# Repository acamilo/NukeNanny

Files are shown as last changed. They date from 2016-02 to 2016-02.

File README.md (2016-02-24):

# NukeNanny
Sensor Node for beehive data collection. 433mhz radio. temp/humidity/ optionally weight.

## Sensors
 * Humidity/Temp (HTU21D)
 * two optional load cells (HX711)

## Radio
 * 433mhz nrf9e5 8051 CPU + Radio
 * 10dBm Tx. 10mm helical antenna 2.5dBi
 
## Battery
 * CR2032 (225mAh)
 * [Rough power budget](https://docs.google.com/spreadsheets/d/1PkM406ndirrwiI1R5EvJM8zMfThP9lIQZCE76__e_ts/edit?usp=sharing) (avg draw 16uA)

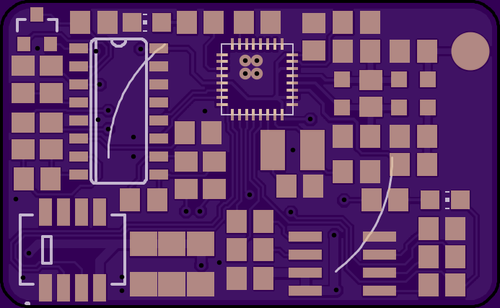
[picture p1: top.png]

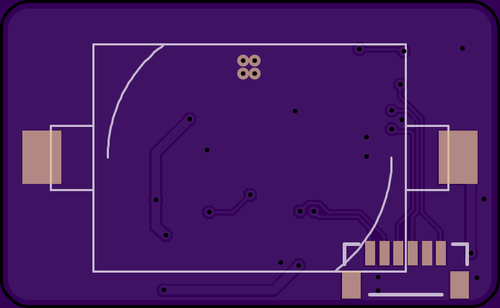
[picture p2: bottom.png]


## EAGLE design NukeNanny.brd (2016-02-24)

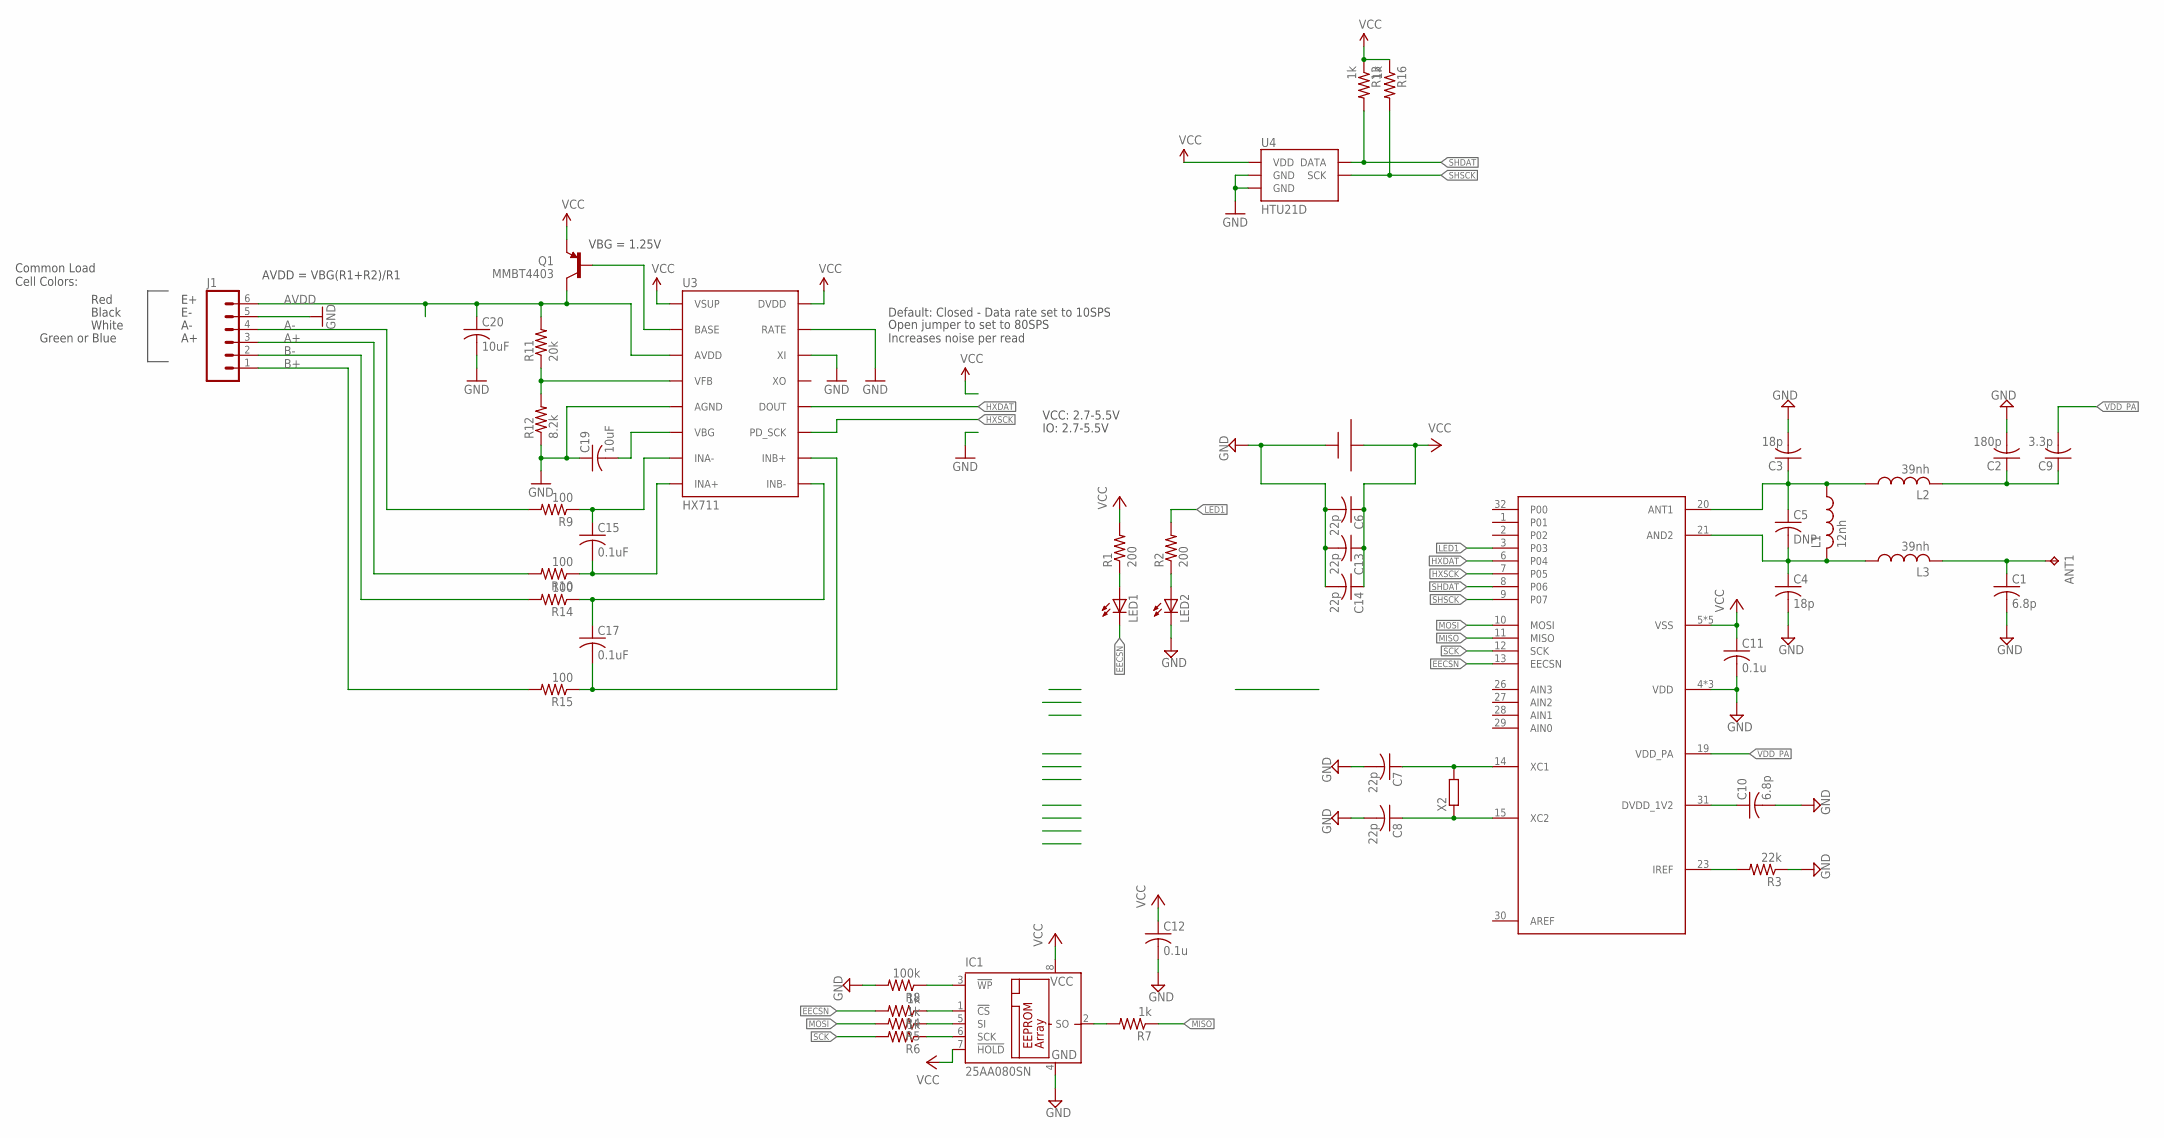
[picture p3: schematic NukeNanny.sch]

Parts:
ANT1: TPB2,54; B2,54
C1, C10: 6.8p; C0805
C2: 180p; C0805
C3, C4: 18p; C0805
C5: DNP; C0805
C6, C13, C14: 22p; C1206
C7, C8: 22p; C0805
C9: 3.3p; C0805
C11, C12: 0.1u; C0805
C15, C17: 0.1uF; C0805
C19, C20: 10uF; C0805
IC1: 25AA080SN; SO-08
J1: M06SMD-1MM; 1X06-1MM
L1: 12nh; L2012C
L2, L3: 39nh; L2012C
LED1, LED2: LEDCHIP-LED0805; CHIP-LED0805
Q1: MMBT4403; SOT23-3
R1, R2: 200; R0805
R3: 22k; R0805
R4, R5, R6, R7, R13, R16: 1k; R0805
R8: 100k; R0805
R9, R10, R14, R15: 100; R0805
R11: 20k; R0805
R12: 8.2k; R0805
U1: CR2032; SMT_CR2032_HOLDER
U3: HX711; SO16
U4: HTU21D
U$1: NRF9E5; 32QFN-THIN
X2: R-EU_R3225; R3225

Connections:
A+: J1.3, R10.2
A-: J1.4, R9.2
AVDD: C20.1, J1.6, Q1.3 (C), R11.2, U3.3 (AVDD)
B+: J1.1, R15.2
B-: J1.2, R14.2
EECSN: LED1.C, R4.2, U$1.13 (EECSN)
GND: C1.2, C2.2, C3.2, C4.2, C6.2, C7.2, C8.2, C10.2, C11.2, C12.2, C13.2, C14.2, C19.1, C20.2, IC1.4 (GND), J1.5, LED2.C, R3.1, R8.2, R12.1, U1.-, U3.5 (AGND), U3.14 (XI), U3.15 (RATE), U4.7 (GND), U4.GND, U$1.4 (VDD), U$1.17 (VDD), U$1.25 (VDD)
HXDAT: U3.12 (DOUT), U$1.6 (P04)
HXSCK: U3.11 (PD_SCK), U$1.7 (P05)
LED1: R2.2, U$1.3
MISO: R7.1, U$1.11 (MISO)
MOSI: R5.2, U$1.10 (MOSI)
unnamed: C4.1, C5.2, L1.2, L3.1, U$1.21 (AND2)
unnamed: C3.1, C5.1, L1.1, L2.1, U$1.20 (ANT1)
unnamed: C10.1, U$1.31 (DVDD_1V2)
unnamed: C2.1, C9.1, L2.2
unnamed: LED1.A, R1.1
unnamed: LED2.A, R2.1
unnamed: ANT1.TP, C1.1, L3.2
unnamed: C8.1, U$1.15 (XC2), X2.1
unnamed: C7.1, U$1.14 (XC1), X2.2
unnamed: IC1.1 (!CS), R4.1
unnamed: IC1.5 (SI), R5.1
unnamed: IC1.6 (SCK), R6.1
unnamed: IC1.2 (SO), R7.2
unnamed: R3.2, U$1.23 (IREF)
unnamed: IC1.3 (!WP), R8.1
unnamed: Q1.1 (B), U3.2 (BASE)
unnamed: R11.1, R12.2, U3.4 (VFB)
unnamed: C19.2, U3.6 (VBG)
unnamed: C17.1, R14.1, U3.9 (INB-)
unnamed: C15.1, R9.1, U3.7 (INA-)
unnamed: C15.2, R10.1, U3.8 (INA+)
unnamed: C17.2, R15.1, U3.10 (INB+)
SCK: R6.2, U$1.12 (SCK)
SHDAT: R13.2, U4.DATA, U$1.8 (P06)
SHSCK: R16.2, U4.SCK, U$1.9 (P07)
VCC: C6.1, C11.1, C12.1, C13.1, C14.1, IC1.7 (!HOLD), IC1.8 (VCC), Q1.2 (E), R1.2, R13.1, R16.1, U1.+, U3.1 (VSUP), U3.16 (DVDD), U4.VDD, U$1.5 (VSS), U$1.16 (VSS), U$1.18 (VSS), U$1.22 (VSS), U$1.24 (VSS)
VDD_PA: C9.2, U$1.19 (VDD_PA)

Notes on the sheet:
VCC: 2.7-5.5V
VBG = 1.25V
AVDD = VBG(R1+R2)/R1
Default: Closed - Data rate set to 10SPS
Open jumper to set to 80SPS Increases noise per read
Red
Black
White
Green or Blue
Common Load Cell Colors:
IO: 2.7-5.5V

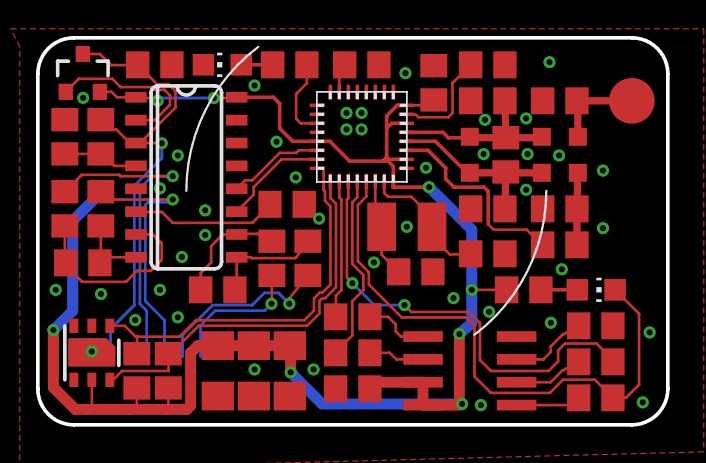
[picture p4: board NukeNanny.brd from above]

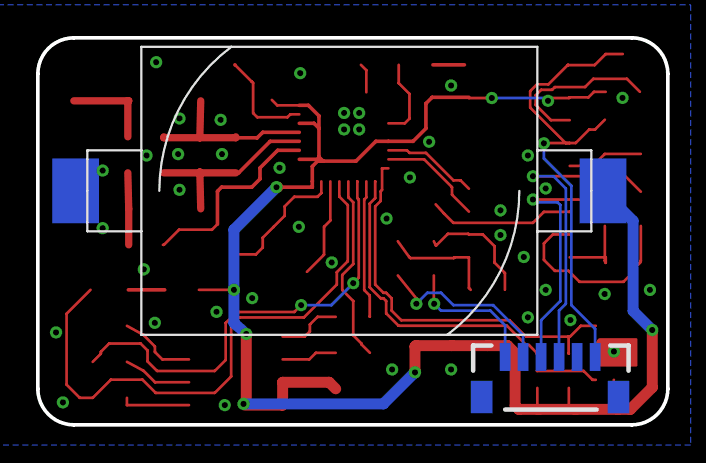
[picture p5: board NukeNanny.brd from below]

Board: 2 copper layers, 35.0 x 21.5 mm, 48 parts (2 on the bottom side), 39 nets.

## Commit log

2016-02-23 Layout done
    [NukeNanny.brd, NukeNanny.sch]
2016-02-24 Changed sensor to HTU21D
    [NukeNanny.brd, NukeNanny.sch]

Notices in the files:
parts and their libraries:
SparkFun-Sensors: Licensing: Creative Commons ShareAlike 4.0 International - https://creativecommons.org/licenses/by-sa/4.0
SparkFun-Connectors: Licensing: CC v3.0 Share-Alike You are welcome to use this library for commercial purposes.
